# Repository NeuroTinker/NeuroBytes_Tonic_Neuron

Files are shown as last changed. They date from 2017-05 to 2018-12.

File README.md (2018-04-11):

# NeuroBytes Tonic Neuron
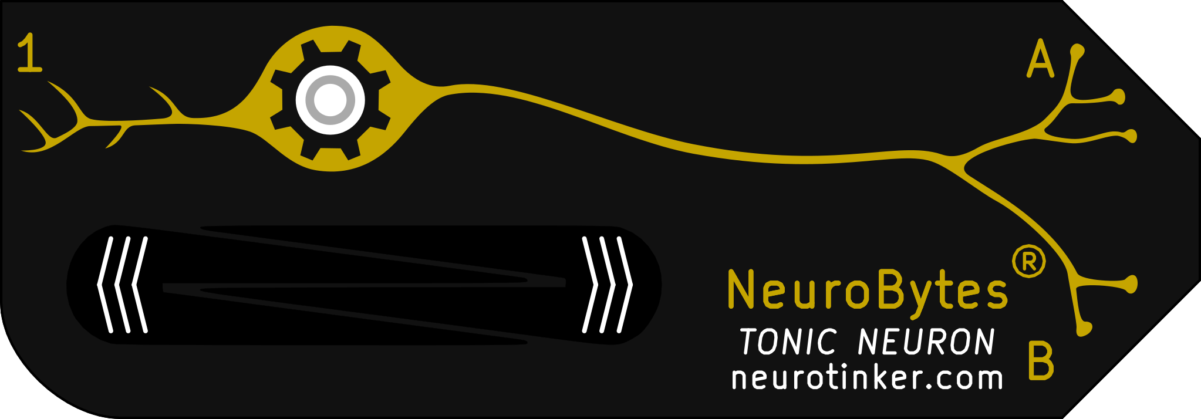
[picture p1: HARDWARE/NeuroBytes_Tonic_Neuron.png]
NeuroBytes Tonic Neuron PCB front

The NeuroBytes Tonic Neuron is an open-source hardware neuron simulator designed and sold by [NeuroTinker, LLC](http://www.neurotinker.com/). 

All NeuroBytes products are based on the ST32L0x series of ARM Cortex-M0+ 32-bit microcontrollers. The boards were designed in KiCad and Inkscape and are released under the terms of the Creative Commons Attribution-ShareAlike 4.0 license, available here: http://creativecommons.org/licenses/by-sa/4.0/. The NeuroBytes Tonic Neuron is Certified Open Source Hardware as defined by [OSHWA](https://www.oshwa.org), certification number US000112.


OSHWA Certification

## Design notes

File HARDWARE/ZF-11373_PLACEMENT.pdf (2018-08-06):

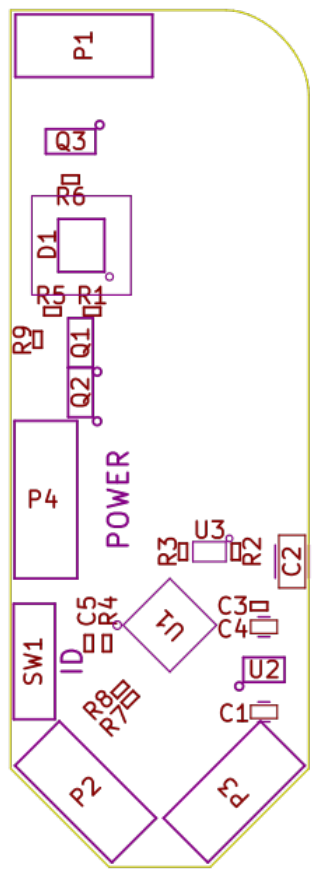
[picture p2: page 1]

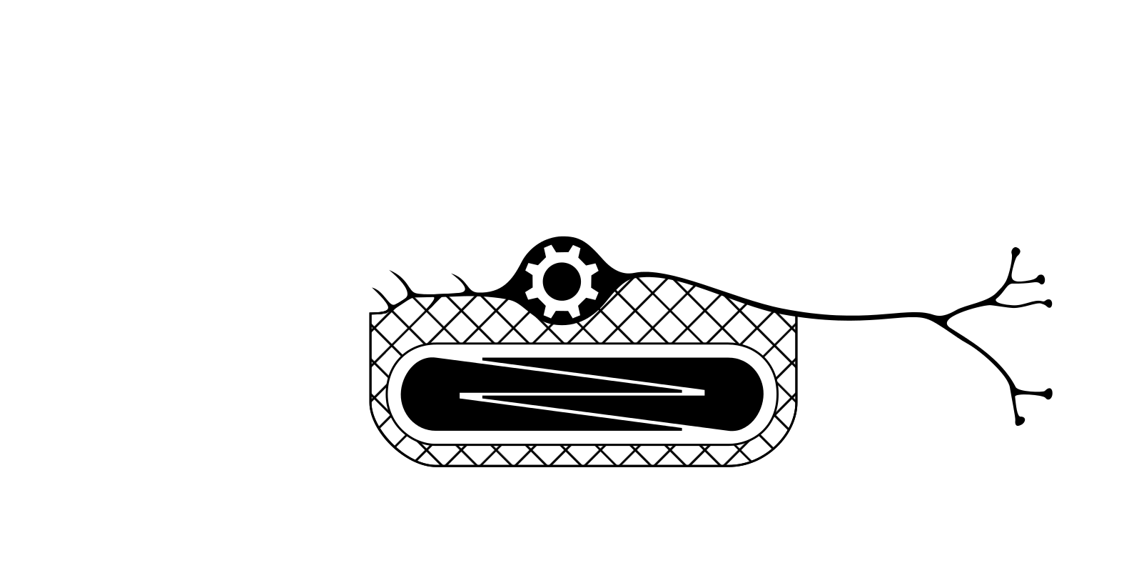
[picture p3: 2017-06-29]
HARDWARE/cu.png

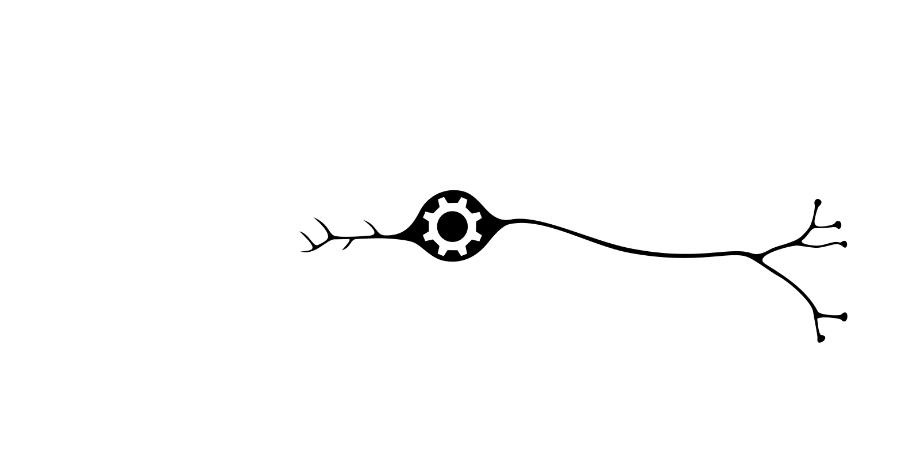
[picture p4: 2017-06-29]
HARDWARE/mask.png

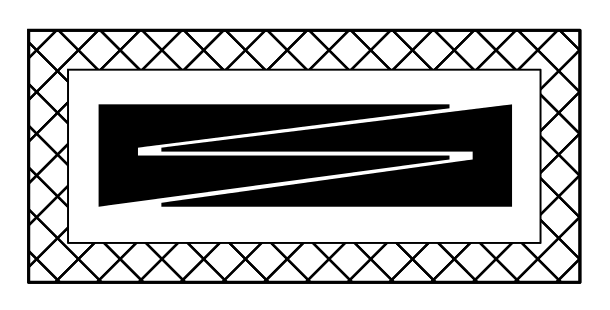
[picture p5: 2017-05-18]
HARDWARE/prototype/cu_front.png

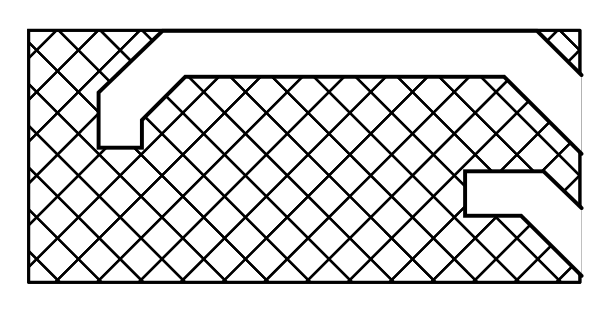
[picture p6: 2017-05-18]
HARDWARE/prototype/cu_back.png

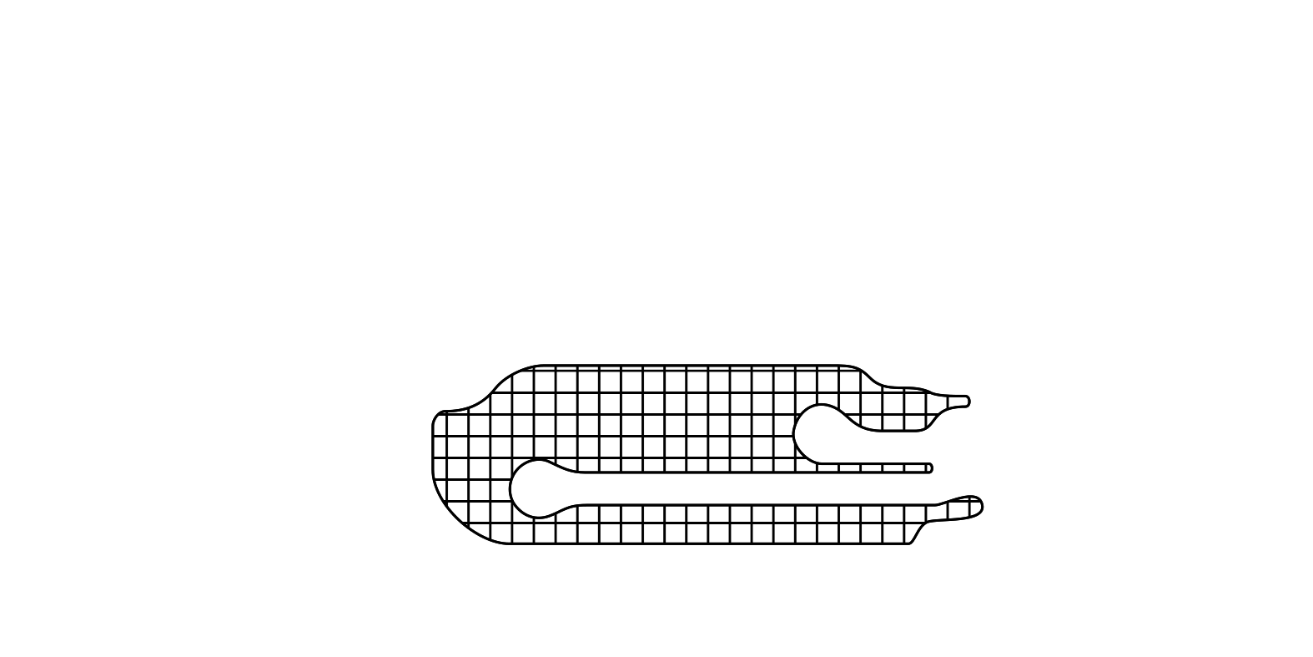
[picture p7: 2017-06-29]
HARDWARE/back.png

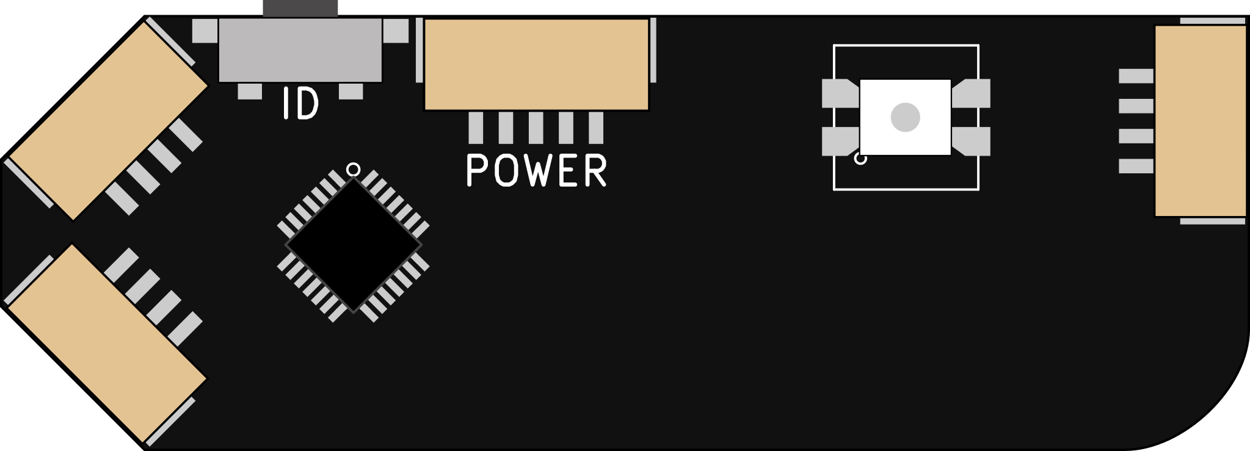
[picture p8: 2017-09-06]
HARDWARE/NeuroBytes_Tonic_Neuron_back.png

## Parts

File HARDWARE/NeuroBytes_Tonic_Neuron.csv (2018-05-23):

Ref | Qty | Value | Link | Mfr | Mfr Part # | Package | RoHS | Subs Allowed
C1 C4 | 2 | 1u | https://www.digikey.com/product-detail/en/taiyo-yuden/LMK107B7105KA-T/587-1242-2-ND/930594 | Taiyo Yuden | LMK107B7105KA-T | C0603 | Yes | Yes
C5 C3 | 2 | 0u1 | https://www.digikey.com/product-detail/en/taiyo-yuden/LMK105BJ104KV-F/587-1227-2-ND/930579 | Taiyo Yuden | LMK105BJ104KV-F | C0402 | Yes | Yes
C2 | 1 | 10u | https://www.digikey.com/product-detail/en/taiyo-yuden/EMK316B7106KL-TD/587-2395-2-ND/2178914 | Taiyo Yuden | EMK316B7106KL-TD | C1206 | Yes | Yes
D1 | 1 | LED_RABG | https://www.digikey.com/product-detail/en/sunled/XZMDKCBDDG45S-9/1497-1257-2-ND/4902045 | SunLED | XZMDKCBDDG45S-9 | SMT | Yes | No
P2 P3 P1 | 3 | CONN_01X04 | https://www.digikey.com/product-detail/en/jst-sales-america-inc/SM04B-GHS-TB-LF-SN/455-1566-2-ND/807788 | JST | SM04B-GHS-TB(LF)(SN) | SMT | Yes | No
P4 | 1 | JST_GH_5-pos | https://www.digikey.com/product-detail/en/jst-sales-america-inc/SM05B-GHS-TB-LF-SN/455-1567-2-ND/807789 | JST | SM05B-GHS-TB(LF)(SN) | SMT | Yes | No
Q1 Q2 Q3 | 3 | Q_NPN_BEC | https://www.digikey.com/product-detail/en/micro-commercial-co/MMBT3904-TP/MMBT3904TPMSTR-ND/717280 | Micro Commercial Co | MMBT3904-TP | SOT23-3 | Yes | Yes
R4 | 1 | JMP | https://www.digikey.com/product-detail/en/yageo/RC0402JR-070RL/311-0.0JRTR-ND/726406 | Yageo | RC0402JR-070RL | R0402 | Yes | Yes
R3 R2 | 2 | 470k | https://www.digikey.com/product-detail/en/yageo/RC0402FR-07470KL/311-470KLRTR-ND/726618 | Yageo | RC0402FR-07470KL | R0402 | Yes | Yes
R1 | 1 | 150 | https://www.digikey.com/product-detail/en/yageo/RC0402FR-07150RL/311-150LRCT-ND/729490 | Yageo | RC0402FR-07150RL | R0402 | Yes | Yes
R5 R6 | 2 | 100 | https://www.digikey.com/product-detail/en/yageo/RC0402FR-07100RL/311-100LRTR-ND/726527 | Yageo | RC0402FR-07100RL | R0402 | Yes | Yes
R7 R8 R9 | 3 | 1k | https://www.digikey.com/product-detail/en/yageo/RC0402FR-071KL/311-1.00KLRTR-ND/726513 | Yageo | RC0402FR-071KL | R0402 | Yes | Yes
SW1 | 1 | SW_PUSH | https://www.digikey.com/product-detail/en/e-switch/TL3330AF130QG/EG4388TR-ND/1426835 | E-Switch | TL3330AF130QG | SMT | Yes | No
U1 | 1 | STM32L011Gx | http://www.mouser.com/ProductDetail/STMicroelectronics/STM32L011G4U6/ | ST Microelectronics | STM32L011G4U6 | 28-UFQFN | Yes | No
U2 | 1 | TLV70033_SOT23-5 | https://www.digikey.com/product-detail/en/on-semiconductor/NCP114BSN330T1G/NCP114BSN330T1GOSTR-ND/6560606 | ON Semiconductor | NCP114BSN330T1G | SOT23-5L | Yes | Yes
U3 | 1 | RClamp0503F | https://www.digikey.com/product-detail/en/semtech-corporation/RCLAMP0503F.TCT/RCLAMP0503F.TCTTR-ND/5113629 | Semtech Corporation | RCLAMP0503F.TCT | 5-TSSOP | Yes | No
BOM made with KICAD_BOM_WIZARD (https://github.com/HashDefineElectronics/KiCad_BOM_Wizard.git)
Generated Wed 23 May 2018 05:25:58 PM CDT

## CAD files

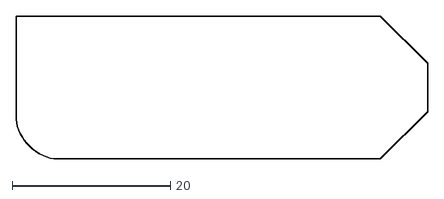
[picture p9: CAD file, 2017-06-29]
HARDWARE/NeuroBytes_Tonic_Neuron.dxf
51.9 x 18.0

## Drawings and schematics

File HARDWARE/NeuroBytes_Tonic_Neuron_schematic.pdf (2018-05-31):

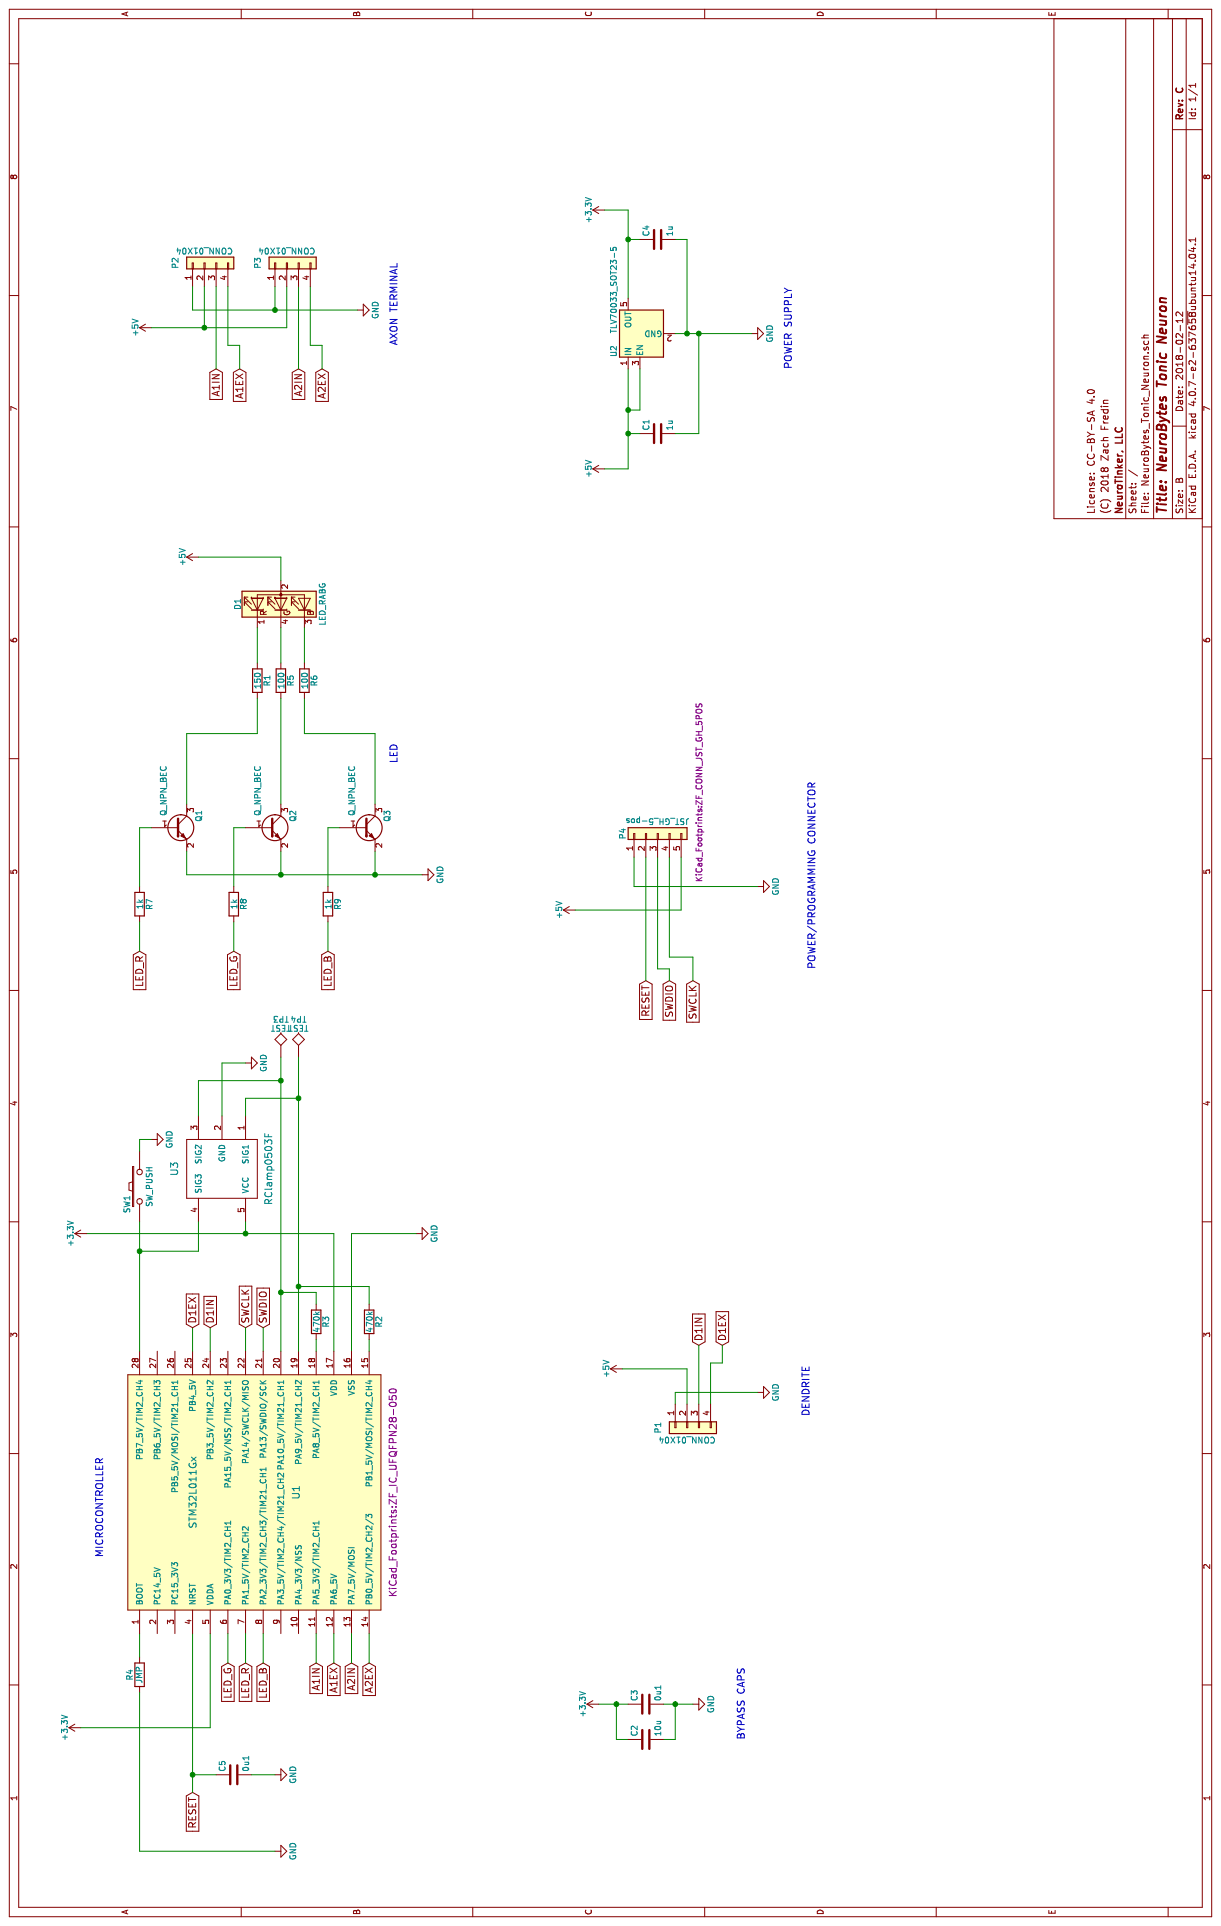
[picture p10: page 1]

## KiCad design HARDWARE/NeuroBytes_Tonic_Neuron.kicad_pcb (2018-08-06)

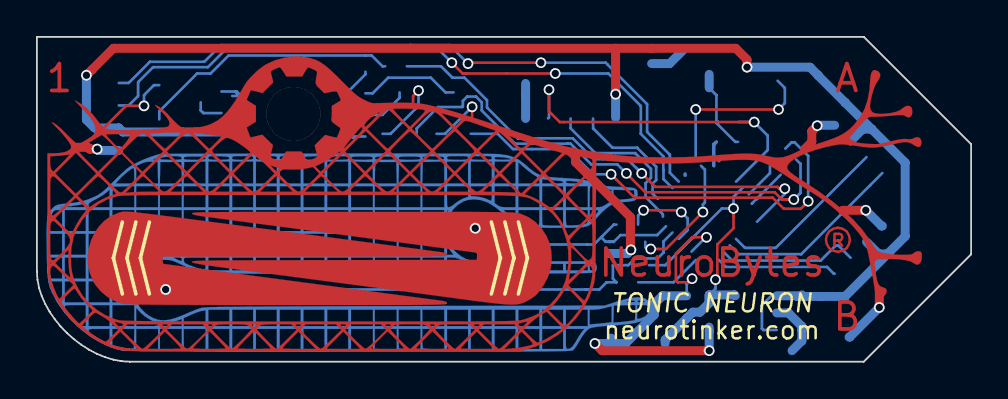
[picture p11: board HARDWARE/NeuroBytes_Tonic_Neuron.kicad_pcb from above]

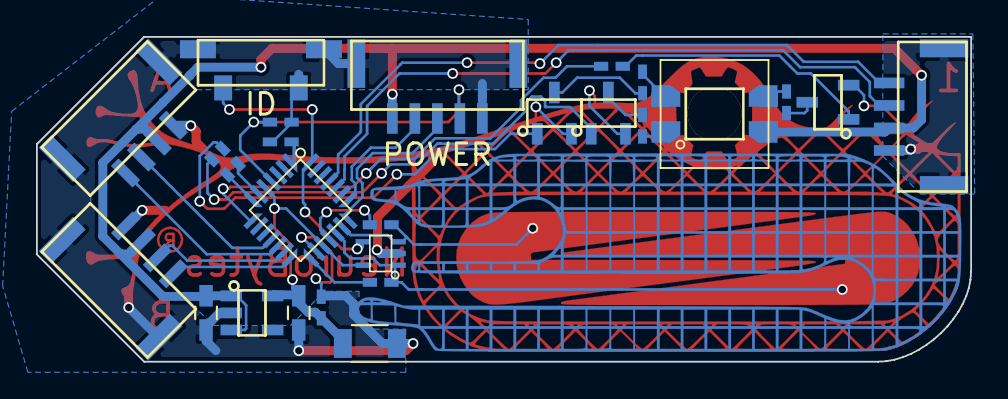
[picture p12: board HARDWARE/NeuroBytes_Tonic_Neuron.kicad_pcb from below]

Board: 2 copper layers, 51.9 x 18.0 mm, 28 parts (26 on the bottom side), 30 nets.

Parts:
C1, C4: 1u; C_0603_HandSoldering
C2: 10u; C_1206
C3, C5: 0u1; ZF_SMD_NonPol_0402_cap
D1: LED_RABG; ZF_LED_RGB_SunLED_XZMDKCBDDG45S-9_cast
P1, P2, P3: CONN_01X04; ZF_CONN_JST_GH
P4: JST_GH_5-pos; ZF_CONN_JST_GH_5POS
Q1, Q2, Q3: Q_NPN_BEC; ZF_SOT23-3L
R1: 150; ZF_SMD_NonPol_0402
R2, R3: 470k; ZF_SMD_NonPol_0402
R4: JMP; ZF_SMD_NonPol_0402
R5, R6: 100; ZF_SMD_NonPol_0402
R7, R8, R9: 1k; ZF_SMD_NonPol_0402
SW1: SW_PUSH; ZF_SW_Momentary_SideMtg
TP3, TP4: TEST; ZF_CONN_1-2_pad
U1: STM32L011Gx; ZF_IC_UFQFPN28-050
U2: TLV70033_SOT23-5; ZF_SOT23-5L
U3: RClamp0503F; ZF_SMD_SOT-353

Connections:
+3V3: C2.1, C3.1, C4.1, U1.5, U1.17, U2.5, U3.5
+5V: C1.1, D1.2, P1.2, P2.2, P3.2, P4.5, U2.1, U2.3
A1EX: P2.4, U1.12
A1IN: P2.3, U1.11
A2EX: P3.4, U1.14
A2IN: P3.3, U1.13
D1EX: P1.4, U1.25
D1IN: P1.3, U1.24
GND: C1.2, C2.2, C3.2, C4.2, C5.2, P1.1, P2.1, P3.1, P4.1, Q1.2, Q2.2, Q3.2, R4.1, SW1.1, U1.16, U2.2, U3.2
LED_B: R9.2, U1.8
LED_G: R8.2, U1.6
LED_R: R7.2, U1.7
unnamed: D1.1, R1.1
unnamed: D1.3, R6.1
unnamed: D1.4, R5.1
unnamed: Q1.1, R7.1
unnamed: Q1.3, R1.2
unnamed: Q2.1, R8.1
unnamed: Q2.3, R5.2
unnamed: Q3.1, R9.1
unnamed: Q3.3, R6.2
unnamed: R2.1, TP4.1, U1.19, U3.1
unnamed: R2.2, U1.15
unnamed: R3.1, TP3.1, U1.20, U3.3
unnamed: R3.2, U1.18
unnamed: R4.2, U1.1
unnamed: SW1.2, U1.28, U3.4
RESET: C5.1, P4.2, U1.4
SWCLK: P4.4, U1.22
SWDIO: P4.3, U1.21

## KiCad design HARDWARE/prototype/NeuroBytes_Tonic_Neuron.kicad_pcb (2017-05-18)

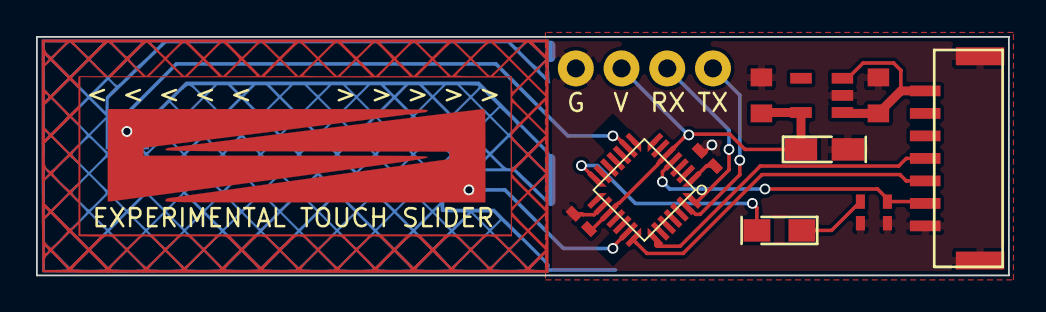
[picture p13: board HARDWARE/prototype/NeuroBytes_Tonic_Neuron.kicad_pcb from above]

Board: 2 copper layers, 54.0 x 13.2 mm, 14 parts (0 on the bottom side), 13 nets.

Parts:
C1, C4: C; ZF_SMD_NonPol_0603
C2: CP; ZF_SMD_pol_1206
C3, C5: C; ZF_SMD_NonPol_0402_cap
D1: LED; ZF_SMD_pol_0805
P1: CONN_01X04; ZF_CONN_1x4-hdr
P12: CONN_01X07; ZF_CONN_JST_GH_7POS
R1, R4: R; ZF_SMD_NonPol_0402
TP3, TP4: TEST; ZF_CONN_1-2_pad
U1: STM32L011Gx; ZF_IC_UFQFPN28-050
U2: LD3985G33R; ZF_SOT23-5L

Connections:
+3V3: C2.1, C3.1, C4.1, P1.2, U1.5, U1.17, U2.5
+5V: C1.1, P12.7, U2.1, U2.3
GND: C1.2, C2.2, C3.2, C4.2, C5.2, P1.1, P12.1, R1.2, R4.1, U1.16, U2.2
unnamed: D1.1, R1.1
unnamed: D1.2, U1.14
unnamed: R4.2, U1.1
unnamed: TP3.1, U1.20
unnamed: TP4.1, U1.9
RESET: C5.1, P12.2, U1.4
SWCLK/MISO: P12.4, U1.22
SWDIO/SCK: P12.3, U1.21
USART2_RX: P1.3, U1.28
USART2_TX: P1.4, U1.27

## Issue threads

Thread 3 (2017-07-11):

Output signals inconsistent to motor neuron

zakqwy, 2017-07-11:
Tonic Neuron sometimes doesn't trigger motor neuron via dendrite 1. Also observed occasional 'always-on' condition after disconnecting and reconnecting cables. Tested motor neuron with other inputs and did not observe issue.

jrwhite, 2018-01-30:
Fixed in the current firmware overhaul.

Closed 2018-01-30.

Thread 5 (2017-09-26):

improve slider interface

zakqwy, 2017-09-26:
experiment with up/down buttons, less resolution, etc.

NeuroTinkerJoe, 2018-01-18:
When updating the resolution, it would be worth respanning the virtual membrane potential so that sliding all the way to the left sets the membrane potential at a hyperpolarized (bluish LED) state, which would result in a neuron that is slightly more difficult to fire than normal. Sort of a high pass filter when in this state, which is physiological with some types of neurons. If there are say 4 bits of resolution with the slider, maybe the leftmost possibility is hyperpolarized, and then when sliding to the right, the next step is normal resting membrane potential, maybe the next 4 are elevated but subthreshold potentials, and the final 10 are suprathreshold that lead to increasing firing frequencies.

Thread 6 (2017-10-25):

multiple inhibitory signals eventually cause action potential

zakqwy, 2017-10-25:

jrwhite, 2018-01-30:
This was happening for the same reason as the interneuron (integer overflow). Fixed in the current firmware.

Closed 2018-01-30.

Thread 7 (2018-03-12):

update firmware so dendrite and both axons work

zakqwy, 2018-03-12:
New boards assembled / tested (w/ ESD protection chip). Update and replace existing stock.

jrwhite, 2018-12-29:
fixed

Closed 2018-12-29.

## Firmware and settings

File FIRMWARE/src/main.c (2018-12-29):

#include <libopencm3/stm32/rcc.h>
#include <libopencm3/stm32/gpio.h>
#include <libopencm3/stm32/timer.h>
#include <libopencm3/cm3/nvic.h>
#include <libopencm3/cm3/systick.h>
#include <libopencm3/stm32/exti.h>
#include <libopencm3/stm32/usart.h>


#include "HAL.h"
#include "comm.h"
#include "neuron.h"

// #define DBG

#define BLINK_TIME			40
#define DATA_TIME			10
#define DEND_PING_TIME		200 // 1000 ms
#define	NID_PING_TIME		200 // 1000 ms
#define SEND_PING_TIME		80 // 80
#define BUTTON_PRESS_TIME	2
#define BUTTON_HOLD_TIME    100
#define LPUART_SETUP_TIME	100
#define CHANGE_NID_TIME		200

int slide_in;

int main(void)
{
	uint8_t		i;

	// counters
	uint32_t	blink_time = 0; // counter for slide_in blink due to NID command
	uint16_t	data_time = 0; // counter for sending data to NID
	uint16_t	send_ping_time = 0; // counter for sending a downstream ping

	uint16_t	last_fire_time = UINT16_MAX;
	uint16_t	current_fire_time = 0;

	uint16_t	fire_delay_time = 0;
	uint8_t		fire_flag = 0;
	uint8_t		fire_tick = 0;

	uint16_t	lpuart_setup_time = 0;

	uint8_t		change_nid_time = 0;
	int16_t		fire_data = 0;
	uint16_t	fire_delay_time_reset = FIRE_DELAY_TIME;
	fire_delay_time_reset = 40; // temporary
	uint16_t	fire_delay_overflow = 0; // used if firing period is less than delay time

	uint16_t	button_press_time = 0; 
	uint8_t		button_armed = 0;
	uint16_t	button_status = 0;

	message_t	message; // staging variable for constructing messages to send to the communications routine

	int adj_slide_in = 0;
	int prev_slide_in = 0;
	int slide_in_buf[30];
	uint8_t slide_in_buf_i;

	// initialize neuron
	neuron_t 	neuron;
	neuronInit(&neuron);

	neuron.dendrites[0].magnitude = 4000;
	neuron.dendrites[0].base_magnitude = 4000;

	// initialize communication buffers
	commInit();

	clock_setup();
	gpio_setup();
	tim_setup();
	systick_setup();
	
	for(;;){
		if (main_tick == 1 && pause_flag == 0){ 
			main_tick = 0;
			
			// check to see if nid ping hasn't been received in last NID_PING_TIME ticks
			if (nid_ping_time > 0){
				nid_ping_time -= 1;
				if (nid_ping_time == 0){
					// nid no longer connected
					nid_distance = 100; // reset nid_keep_alive
					nid_pin = 0; // clear the nid pin
					nid_pin_out = 0;
					nid_i = NO_NID_I;
				}
			}
			
			// send a downstream ping every SEND_PING_TIME ticks
			if (send_ping_time++ > SEND_PING_TIME){
				// send downstream ping through axon
				addWrite(DOWNSTREAM_BUFF, downstream_ping_message);
				send_ping_time = 0;
			}

			if (lpuart_setup_time < LPUART_SETUP_TIME){
				lpuart_setup_time += 1;
			} else if (lpuart_setup_time == LPUART_SETUP_TIME){
				lpuart_setup_time += 1;
				#ifndef DBG
				lpuart_setup();
				#endif
			}

			/*
				nid_channel is the current channel, if any, that the NeuroByte is using to communicate
				with the NID. nid_channel should be cleared when NID tries to set a new NeuroByte to 
				identify_channel.

				The communication routine sets identify_time to zero when a new identify command is received.
			*/

			// check for clear channel command
			if (identify_time < IDENTIFY_TIME){
				if (identify_time == 0){
					if ((identify_channel == 0) || (identify_channel == nid_channel)){
						nid_channel = 0;
					}
				}
				identify_time += 1;
			}

			// check identify button
			button_status = gpio_get(PORT_IDENTIFY, PIN_IDENTIFY);

			// if identify button is pressed and identify_time < IDENTIFY_TIME (i.e. NID sent 'identify'' message), set new nid_channel
			if (button_status == 0){
				// debounce
				button_press_time += 1;
				if (button_press_time >= BUTTON_HOLD_TIME){
					button_armed = 2;
					blink_flag = 1;
				} else if (button_press_time >= BUTTON_PRESS_TIME){
					button_armed = 1;
				}
			} else{
				// button not pressed
				if (button_armed == 0){
					button_press_time = 0;
				} else if (button_armed == 1 && nid_i != NO_NID_I){
					nid_channel = identify_channel;
					identify_time = 1;
					button_armed = 0;
				} else if (button_armed == 2){
					// put held-down functionality here
					button_armed = 0;
				}
				button_press_time = 0;
			}

			/*
				Check dendrites for pings and adjut pins accordingly.
				Also check dendrites for pulses and calculate new membrane potential.
			*/

			// decay the firing potential
			checkDendrites(&neuron);
			membraneDecayStep(&neuron);
			dendriteDecayStep(&neuron);
			// current membrane potential comes from dendrites and any left over firing potential
			neuron.potential = calcNeuronPotential(&neuron);
			neuron.potential += neuron.fire_potential;
			neuron.fire_potential += neuron.leaky_current;
			current_fire_time += 1;
			
			// send current membrane potential to NID if currently identified by NID
			if (nid_channel != 0){
				// send data every DATA_TIME ticks
				if (data_time++ > DATA_TIME){
					if (fire_data > 0){
						if (fire_data == 1){
							message.message = (((uint32_t) DATA_MESSAGE)) | ((uint16_t) HYPERPOLARIZATION);
							fire_data = 0;						
						} else {
							message.message = (((uint32_t) DATA_MESSAGE)) | ((uint16_t) fire_data);	
							fire_data = 1;						
						}
					} else {
						message.message = (((uint32_t) DATA_MESSAGE)) | ((uint16_t) neuron.potential);						
					}
					data_time = 0;
					message.length = 32;
					message.message |= (nid_channel << 21);
					addWrite(NID_BUFF,(const message_t) message);
				}
			}

			// if membrane potential is greater than threshold, fire
			if (neuron.potential > MEMBRANE_THRESHOLD){
				// fire for determined pulse width
				neuron.state = FIRE;
				neuron.fire_potential = HYPERPOLARIZATION;
				neuron.fire_time = PULSE_LENGTH;
				for (i=0; i<NUM_DENDS; i++){
					neuron.dendrites[i].current_value = 0;
					neuron.dendrites[i].state = OFF;
				}

				fire_data = neuron.potential;

				// send downstream pulse
				if (fire_delay_time == 0){
					fire_delay_time = fire_delay_time_reset;
					fire_delay_overflow = 0;
				} else {
					fire_delay_overflow = fire_delay_time_reset - fire_delay_time;
				}
				fire_flag = 1;
			} else if (neuron.potential < HYPERPOLARIZATION){
				neuron.potential = HYPERPOLARIZATION;
			}

			
			if (fire_delay_time > 0){
				fire_delay_time -= 1;
			} else if (fire_flag == 1){
				if (fire_delay_overflow > 0)
					fire_delay_time = fire_delay_overflow; // TODO: make this an actual FIFO buffer of fire timings
				fire_flag = 0;
				addWrite(DOWNSTREAM_BUFF, pulse_message);
			}


			slide_in = get_slider_position();
			adj_slide_in = slide_in - prev_slide_in;
			prev_slide_in = slide_in;
			// something something

			if (slide_in > 0){ // >
				neuron.leaky_current = slide_in* 25 / 12;
			}

			// if (fire_tick-- == 0){
			// 	addWrite(DOWNSTREAM_BUFF, PULSE_MESSAGE);
			// 	if (neuron.leaky_current < 100){
			// 		fire_tick = 70;
			// 	} else if (neuron.leaky_current < 300){
			// 		fire_tick = 70 - (neuron.leaky_current - 100) / 5; // leaky_current between 131 and 352
			// 		// fire_tick = (1, 46) ~=> 10ms to 520ms 
			// 	}else{
			// 		fire_tick = 15;
			// 	}
			// }

			
			/*
			if (slide_in> -1)
			{
				setslide_in0, 0, slide_in)
			}
			*/
			
			if (blink_flag != 0){
				setLED(200,0,300);
				blink_time = 1;
				blink_flag = 0;
			} else if (blink_time > 0){
				if (++blink_time == BLINK_TIME){
					setLED(200,0,200);
					blink_time = 0;
				}
			} else if (neuron.state == FIRE){
				neuron.fire_time -= 1;
				if (neuron.fire_time == 0){
					neuron.state = INTEGRATE;
				}
				if (neuron.learning_state == HEBB){
					setLED(200,100,200);
				} else{
					LEDFullWhite();
				}
			} else if (neuron.state == INTEGRATE){
				if (neuron.potential > 10000){
					setLED(200,0,0);
				} else if (neuron.potential > 0){
					setLED(neuron.potential / 50, 200 - (neuron.potential / 50), 0);
				} else if (neuron.potential < -10000){
					setLED(0,0, 200);
				} else if (neuron.potential < 0){
					setLED(0, 200 + (neuron.potential / 50), -1 * neuron.potential / 50);
				} else{
					setLED(0,200,0);
				}
			}
			// if (neuron.state == FIRE){
			// 	neuron.fire_time -= 1;
			// 	if (neuron.fire_time == 0){
			// 		neuron.state = INTEGRATE;
			// 	}
			// 	setslide_in600,9600,9600);
			// } else if (neuron.state == INTEGRATE){
			// 	if (neuron.potential > 10000){
			// 		setslide_in00,0,0);
			// 	} else if (neuron.potential > 0){
			// 		setslide_ineuron.potential / 50, 200 - (neuron.potential / 50), 0);
			// 	} else if (neuron.potential < -10000){
			// 		setslide_in,0, 200);
			// 	} else if (neuron.potential < 0){
			// 		setslide_in, 200 + (neuron.potential / 50), -1 * neuron.potential / 50);
			// 	} else{
			// 		setslide_in,200,0);
			// 	}
			// }
			// if (neuron.leaky_current < 100){
			// 	setslide_in,100,0);
			// }else if (neuron.leaky_current < 300){
			// 	setslide_inneuron.leaky_current - 100), 100, 0);
			// } else {
			// 	setslide_in00,100,0);
			// }
		}
	}
}

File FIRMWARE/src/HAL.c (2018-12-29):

#include "HAL.h"
#include <string.h>
#include "comm.h"


volatile uint8_t touch_tick = 0;
volatile int sensor0_time = 0;
volatile int sensor1_time = 0;
volatile uint8_t main_tick = 0;
volatile uint16_t tick = 0;
volatile uint8_t read_tick = 0;
volatile uint32_t main_tick_count = 0;
volatile uint8_t comms_tick = 0;

volatile uint16_t active_input_pins[NUM_INPUTS] = {[0 ... 3] = 0};

volatile uint8_t active_input_tick[NUM_INPUTS] = {[0 ... 3] = 0};

volatile uint16_t active_output_pins[NUM_INPUTS] = {PIN_AXON1_EX, PIN_AXON2_EX, 0, 0};

volatile uint32_t dendrite_pulses[NUM_DENDS] = {0};
volatile uint8_t dendrite_pule_count = 0;

uint32_t active_input_ports[NUM_INPUTS] = {
	PORT_AXON1_IN,
	PORT_AXON2_IN,
	PORT_DEND1_EX,
	PORT_DEND1_IN
};

uint32_t active_output_ports[NUM_INPUTS] = {
	PORT_AXON1_EX,
	PORT_AXON2_EX,
	PORT_DEND1_EX,
	PORT_DEND1_IN
};

const uint16_t complimentary_pins[NUM_INPUTS] = {
	PIN_AXON1_EX,
	PIN_AXON2_EX,
	PIN_DEND1_IN,
	PIN_DEND1_EX
};

const uint32_t complimentary_ports[NUM_INPUTS] = {
	PORT_AXON1_EX,
	PORT_AXON2_EX,
	PORT_DEND1_IN,
	PORT_DEND1_EX
};

volatile uint8_t dendrite_pulse_flag[NUM_INPUTS] = {[0 ... NUM_INPUTS-1] = 0};
volatile uint8_t dendrite_ping_flag[NUM_INPUTS] = {[0 ... NUM_INPUTS-1] = 0};

static uint32_t fingerprint[3] __attribute__((section (".fingerprint"))) __attribute__ ((__used__)) = {
	4, // device id
	2, // firmware version
	0  // unique id
};

bool checkVersion(uint32_t device_id, uint32_t version) {return (device_id == fingerprint[0]) && (version = fingerprint[1]) ? true : false;}

void clock_setup(void)
{
	// STM32F0 command:	rcc_clock_setup_in_hsi_out_48mhz();
	rcc_set_sysclk_source(RCC_HSI16);
	rcc_osc_on(RCC_HSI16);
}

void systick_setup()
{
    systick_set_clocksource(STK_CSR_CLKSOURCE_EXT);
    STK_CVR = 0;
    systick_set_reload(60);
    systick_counter_enable();
    systick_interrupt_enable();
}

void sys_tick_handler(void)
{    
	switch (touch_tick){
        
		case 0:
			start_touch(SENSOR0);
			touch_tick++;
			break;
		case 1:
			sensor0_time = get_touch(SENSOR0);
			touch_tick++;
			break;
		case 2:
			start_touch(SENSOR1);
			touch_tick++;
			break;
		case 3:
			sensor1_time = get_touch(SENSOR1);
			touch_tick = 0;
			break;
		default:
			touch_tick = 0;
			break;
	}

	if (++tick >= 150){
		main_tick = 1;
		tick = 0;
	}

	if (tick % 3 == 0){
		if (read_tick++ >= 2){
			writeBit();
			read_tick = 0;
		}

		readBit(read_tick);
	}
	
}

void gpio_setup(void)
{
	/*	Enable GPIO clocks */
	rcc_periph_clock_enable(RCC_GPIOA);
	rcc_periph_clock_enable(RCC_GPIOB);
	rcc_periph_clock_enable(RCC_GPIOC);

	rcc_peripheral_enable_clock(&RCC_APB2ENR, RCC_APB2ENR_SYSCFGEN);

	/*	Set up LED pins
		Alternative Function Mode with no pullup/pulldown
		Output options: push-pull, high speed
		PIN_R_LED (PA1): AF2, TIM2_CH2
		PIN_G_LED (PA0): AF2, TIM2_CH1
		PIN_B_LED (PA2): AF2, TIM2_CH3
	*/

	gpio_mode_setup(PORT_R_LED, GPIO_MODE_AF, GPIO_PUPD_NONE, PIN_R_LED);
	gpio_mode_setup(PORT_G_LED, GPIO_MODE_AF, GPIO_PUPD_NONE, PIN_G_LED);
	gpio_mode_setup(PORT_B_LED, GPIO_MODE_AF, GPIO_PUPD_NONE, PIN_B_LED);
	gpio_set_output_options(PORT_R_LED, GPIO_OTYPE_PP, GPIO_OSPEED_HIGH, PIN_R_LED);
	gpio_set_output_options(PORT_G_LED, GPIO_OTYPE_PP, GPIO_OSPEED_HIGH, PIN_G_LED);
	gpio_set_output_options(PORT_B_LED, GPIO_OTYPE_PP, GPIO_OSPEED_HIGH, PIN_B_LED);
	gpio_set_af(PORT_R_LED, GPIO_AF2, PIN_R_LED);
	gpio_set_af(PORT_G_LED, GPIO_AF2, PIN_G_LED);
	gpio_set_af(PORT_B_LED, GPIO_AF2, PIN_B_LED);

	/*	Set up touch sensor pins as floating AF pins */
	gpio_mode_setup(PORT_TOUCH0_SENSE, GPIO_MODE_AF, GPIO_PUPD_NONE, PIN_TOUCH0_SENSE);
	gpio_mode_setup(PORT_TOUCH1_SENSE, GPIO_MODE_AF, GPIO_PUPD_NONE, PIN_TOUCH1_SENSE);
	gpio_set_af(PORT_TOUCH0_SENSE, GPIO_AF0, PIN_TOUCH0_SENSE);
	gpio_set_af(PORT_TOUCH1_SENSE, GPIO_AF5, PIN_TOUCH1_SENSE);

	/*	Set up touch sensor resistor pins and set them low to start */
    gpio_mode_setup(PORT_TOUCH0_RES, GPIO_MODE_OUTPUT, GPIO_PUPD_PULLDOWN, PIN_TOUCH0_RES);
    gpio_mode_setup(PORT_TOUCH1_RES, GPIO_MODE_OUTPUT, GPIO_PUPD_PULLDOWN, PIN_TOUCH1_RES);

	gpio_clear(PORT_TOUCH0_RES, PIN_TOUCH0_RES);
	gpio_clear(PORT_TOUCH1_RES, PIN_TOUCH1_RES);

	gpio_mode_setup(PORT_IDENTIFY, GPIO_MODE_INPUT, GPIO_PUPD_PULLUP, PIN_IDENTIFY);

    setAsInput(PORT_AXON1_IN, PIN_AXON1_IN);
    setAsInput(PORT_AXON2_IN, PIN_AXON2_IN);
	setAsInput(PORT_DEND1_IN, PIN_DEND1_IN);
    setAsInput(PORT_DEND1_EX, PIN_DEND1_EX);
    
	setAsOutput(PORT_AXON1_EX, PIN_AXON1_EX);
	setAsOutput(PORT_AXON2_EX, PIN_AXON2_EX);

    // enable external interrupts;
	nvic_enable_irq(NVIC_EXTI4_15_IRQ);
	nvic_enable_irq(NVIC_EXTI2_3_IRQ);

	nvic_set_priority(NVIC_EXTI4_15_IRQ, 0);
	nvic_set_priority(NVIC_EXTI2_3_IRQ, 0);
}

void lpuart_setup(void)
{
	// seutp lpuart interface (for communicating with NID)
	// NOTE: this ocnverts the swd interface to lpuart so debugging with swd will be disables
	rcc_periph_clock_enable(RCC_LPUART1);

	gpio_mode_setup(PORT_LPUART1_RX, GPIO_MODE_AF, GPIO_PUPD_NONE, PIN_LPUART1_RX);
	gpio_mode_setup(PORT_LPUART1_TX, GPIO_MODE_AF, GPIO_PUPD_NONE, PIN_LPUART1_TX);

	gpio_set_af(PORT_LPUART1_RX, GPIO_AF6, PIN_LPUART1_RX);
	gpio_set_af(PORT_LPUART1_TX, GPIO_AF6, PIN_LPUART1_TX);

	USART_BRR(LPUART1) = 0x1A0AA; // 38400 baud
	usart_set_databits(LPUART1, 8);  // USART_CR1_M
	usart_set_stopbits(LPUART1, USART_STOPBITS_1); //USART_CR2_STOP
	usart_set_mode(LPUART1, USART_MODE_TX_RX); //USART_CR1_RE USART_CR1_TE
	usart_set_parity(LPUART1, USART_PARITY_NONE);// USART_CR1_PS USART_CR1_PCE
	usart_set_flow_control(LPUART1, USART_FLOWCONTROL_NONE); // USART_CR3_RTSE USART_CR3_CTSE

	usart_enable(LPUART1); // USART_CR1_UE

	// enable interrupts
	nvic_enable_irq(NVIC_LPUART1_IRQ);
	usart_enable_rx_interrupt(LPUART1); // USART_CR1_RXNEIE
    USART_CR1(LPUART1) |= USART_CR1_RE;
    USART_CR1(LPUART1) |= USART_CR1_TE;
}

void lpuart1_isr(void)
{
    if ((USART_ISR(LPUART1) & USART_ISR_RXNE) != 0){
        readNID();
        USART_RQR(LPUART1) = 0b1000;
        USART_CR1(LPUART1) |= USART_CR1_RE;
    } else if ((USART_ISR(LPUART1) & USART_ISR_TXE) != 0){
        /* USART_CR1(LPUART1) |= USART_CR1_TE; */
        writeNID();
        USART_RQR(LPUART1) |= USART_RQR_TXFRQ;
    }
    USART_ICR(LPUART1) = USART_ISR(LPUART1);
}

void setAsInput(uint32_t port, uint32_t pin)
{
	
	// setup gpio as an input pin
	gpio_mode_setup(port, GPIO_MODE_INPUT, GPIO_PUPD_PULLDOWN, pin);
	gpio_set_output_options(port, GPIO_OTYPE_PP, GPIO_OSPEED_LOW, pin);

	// setup interrupt for the pin going high
	exti_select_source(pin, port);
	exti_set_trigger(pin, EXTI_TRIGGER_RISING);
	exti_enable_request(pin);
	exti_reset_request(pin);

}

void setAsOutput(uint32_t port, uint32_t pin)
{
	// disable input interrupts
	exti_disable_request(pin);

	// setup gpio as an output pin. pulldown
	gpio_mode_setup(port, GPIO_MODE_OUTPUT, GPIO_PUPD_PULLDOWN, pin);
}
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

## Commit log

2017-05-18 Initial commit. Pulled in libopencm3 and Schematic_Lib libraries. First PCB spin (not yet tested!).
    [NeuroBytes_Tonic_Neuron.kicad_pcb, NeuroBytes_Tonic_Neuron.sch]
2017-05-19 First commit of new firmware. LED seems to work and the chip isn't fried. No touch sensor or serial stuff yet.
2017-05-19 Trying to write an STM32L0 USART driver. doesn't work yet.
    [HAL.c, HAL.h, main.c]
2017-05-19 Got basic USART functionality working following libopencm3 STM32Fx templates and examples. Implemented mini-printf from https://github.com/mludvig/mini-printf (as normal printf is too heavy). Test pr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
    [HAL.c, HAL.h, main.c]
2017-05-19 Moved mini-printf readme file to main directory (and renamed)
2017-05-19 Additional touch sensor tests. Not working with gpio_get() function. Need to try pin change interrupts.
    [HAL.c, main.c]
2017-05-23 Got a 3-bit resolution touch slider demo working using TIM21 capture inputs. Fades the LED with position and outputs raw value over USART2.
2017-06-29 fresh clone with current firmware. added new PCB design -- bipolar neuron graphics, etc.
    [NeuroBytes_Tonic_Neuron.dxf, NeuroBytes_Tonic_Neuron.kicad_pcb, NeuroBytes_Tonic_Neuron.sch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]
2017-07-08 removed miniprintf stuff. updated firmware for new board with external resistors for touch slider. currently runs test program that maps finger position to blue LED color.
    [NeuroBytes_Tonic_Neuron.kicad_pcb, NeuroBytes_Tonic_Neuron.sch]
2017-08-11 changed to 5-pin JST GH connector for power / prog
    [NeuroBytes_Tonic_Neuron.kicad_pcb, NeuroBytes_Tonic_Neuron.sch]
2017-08-11 changed fingerprint address
2017-08-11 changed fingerprint
2017-08-28 added kicad text to *.svg. added *.png export of board front.
2017-09-06 create readme.md w/ pcb render image
2017-09-22 added .gitignore. cleaned up .fingerprint
2017-09-23 changed to single NPN transitors and non-networked resistors. still need to finish routing.
    [NeuroBytes_Tonic_Neuron.kicad_pcb, NeuroBytes_Tonic_Neuron.sch]
2017-09-25 finished routing with discrete NPN transitors and resistors
    [NeuroBytes_Tonic_Neuron.kicad_pcb]
2017-10-01 updated BOM labels. missing link and part number for R2 and R3.
    [NeuroBytes_Tonic_Neuron.sch]
2017-10-01 Reloaded netlist. Added notes to F.Fab layer. Generated production files.
    [NeuroBytes_Tonic_Neuron.kicad_pcb]
2017-10-03 pulled back mask on dendrite and axon terminal labels. other minor PCB updates.
    [NeuroBytes_Tonic_Neuron.kicad_pcb]
2017-10-03 minor page layout updates
    [NeuroBytes_Tonic_Neuron.kicad_pcb, NeuroBytes_Tonic_Neuron.sch]
2017-10-04 BOM updates. Regenerated netlist.
    [NeuroBytes_Tonic_Neuron.csv, NeuroBytes_Tonic_Neuron.sch]
2017-10-04 pulled front paste off touch pads
    [NeuroBytes_Tonic_Neuron.kicad_pcb]
2017-11-30 updated license to CC-BY-SA 4.0. updated readme.md. added drawing no. to PCB.
    [NeuroBytes_Tonic_Neuron.kicad_pcb]
2018-01-25 fixed bugs with comms
    [HAL.c, HAL.h]
2018-01-25 fixed LED
2018-01-31 switched to old pinout
2018-01-31 fixed for old pinout
    [HAL.c]
2018-01-31 changed to RClamp0503F for ESD protection (touch slider, switch, 3v3). ordered 30 PCBs.
    [NeuroBytes_Tonic_Neuron.kicad_pcb, NeuroBytes_Tonic_Neuron.sch]
2018-03-08 updated ESD protection stuff. minor PCB render updates.
    [NeuroBytes_Tonic_Neuron.kicad_pcb, NeuroBytes_Tonic_Neuron.sch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]
2018-04-10 fixed weird inhib/excit bug
    [HAL.h, main.c]
2018-05-23 generated fab files and BOM
    [NeuroBytes_Tonic_Neuron-B.Cu.gbr, NeuroBytes_Tonic_Neuron-B.Mask.gbr, NeuroBytes_Tonic_Neuron-B.Paste.gbr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]
2018-05-23 updated INSERT attribute. regenerated *.pos file.
    [NeuroBytes_Tonic_Neuron.kicad_pcb]
2018-05-31 added schematic *.pdf
2018-08-06 updated footprints to include B.Fab outlines. minor routing changes. poured ground plane around connectors. re-generated Gerbers. added placement pdf.
    [NeuroBytes_Tonic_Neuron-B.Cu.gbr, NeuroBytes_Tonic_Neuron-B.Fab.gbr, NeuroBytes_Tonic_Neuron-B.Mask.gbr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]
2018-08-08 regen Gerbers and drill file
    [NeuroBytes_Tonic_Neuron-B.Cu.gbr, NeuroBytes_Tonic_Neuron-B.Fab.gbr, NeuroBytes_Tonic_Neuron-B.Mask.gbr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]
2018-12-29 increased LED brightness
2018-12-29 increased LED brightness for APs

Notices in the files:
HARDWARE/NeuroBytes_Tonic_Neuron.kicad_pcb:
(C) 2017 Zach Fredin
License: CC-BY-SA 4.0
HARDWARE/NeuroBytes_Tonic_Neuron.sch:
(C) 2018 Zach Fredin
